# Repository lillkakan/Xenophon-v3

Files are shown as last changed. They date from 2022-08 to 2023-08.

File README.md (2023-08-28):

# Xenophon v3 split keyboard

Xenophon is a split keyboard with a design based on the ErgoDox EZ but for less keys for the thumps and another layout for the side keys.

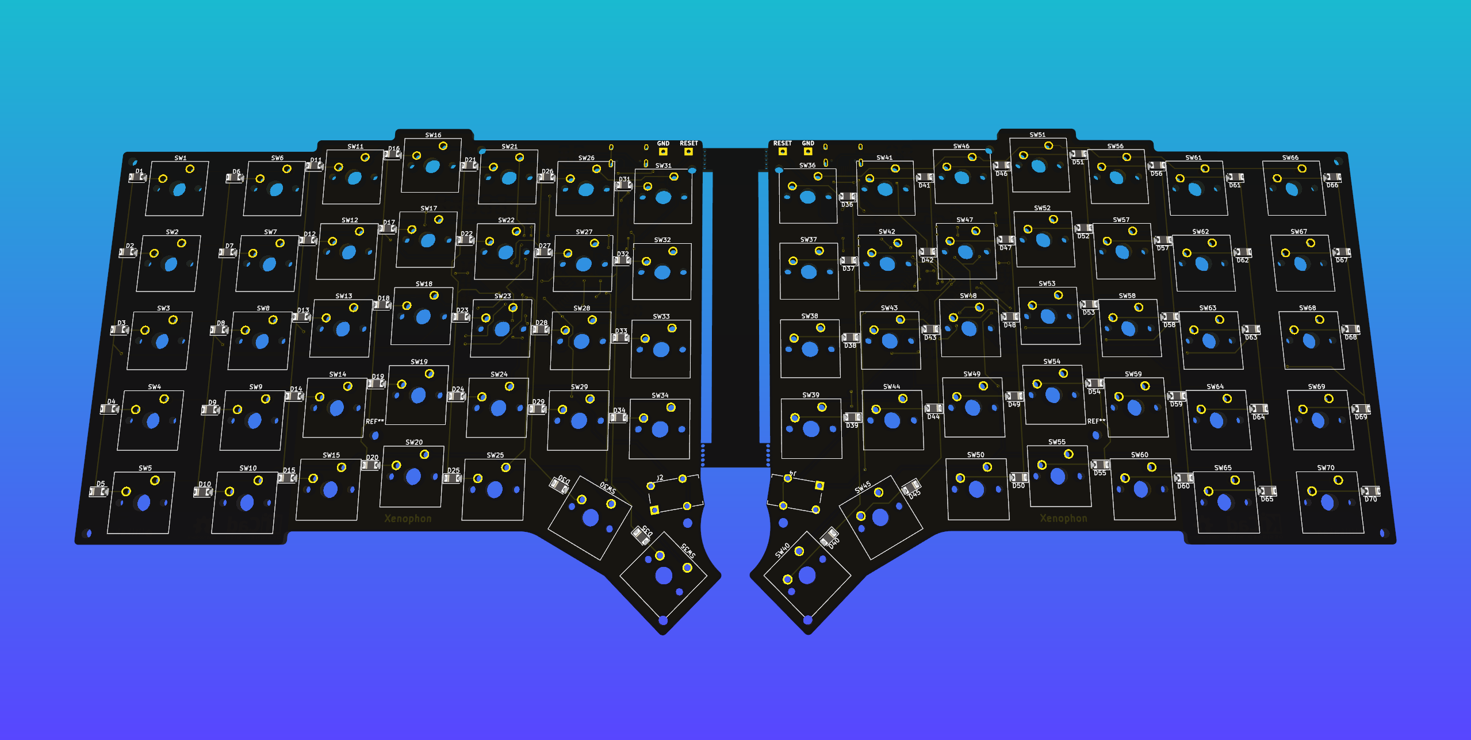
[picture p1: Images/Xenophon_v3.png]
The PCB for the keyboard.


## Features

### Ortholinear design

The keyboard features an ortholinear design based on the ErgoDox EZ.

### 70 buttons

The keyboard features 70 buttons to replicate a standard 60% keyboard as much as possible.
The Default layout is in swedish and has all the letters and numbers.

### TRS jack connection

The PCB is designed with a trs jack nicley placed between the tilted keys.
The two processors sent data through the serial bitbang protocol.

### Smart flashing design

With Usb on both sides it's easy to flash both processors.

### USB-C

The PCB features two usb type c ports with capability to connect via a usb-c to usb-c cable or a standard usb-c to usb-a cable.

### 3D printable chassi

The chassi for the keyboard is 3D printable and is designed to be as small as possible while still protecting the PCB and the electrical components.

## Made with

Quantum Mechanical Keyboard Firmware: [qmk_firmware](https://github.com/qmk/qmk_firmware)

### Made with help from

Keyboard layout editor: [keyboard-layout-editor.com](http://www.keyboard-layout-editor.com/)

Parametric Mechanical Keycap Library: [KeyV2](https://github.com/rsheldiii/KeyV2)

Keyboard Firmware Builder: [kbfirmware.com](https://kbfirmware.com/)

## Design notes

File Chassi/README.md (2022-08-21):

# Xenophon

The base is made using FreeCAD and can be 3D printed and applied to the PCB directly.

The PCB features small stud holes which fits on the studs on the chassi.
Because these holes are small there is a stud tester i printed to confirm that my 3D printers settings would work.

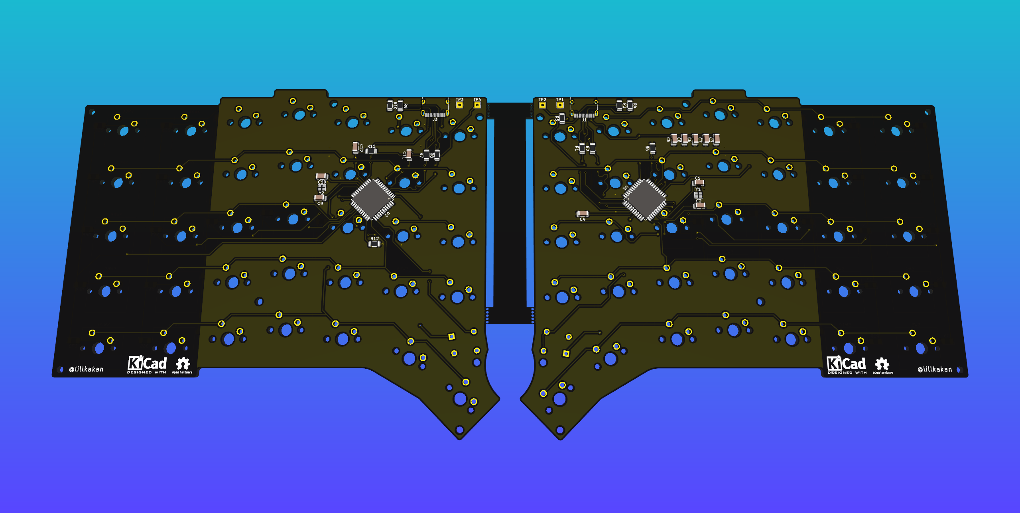
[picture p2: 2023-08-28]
Images/Xenophon_v3_back.png

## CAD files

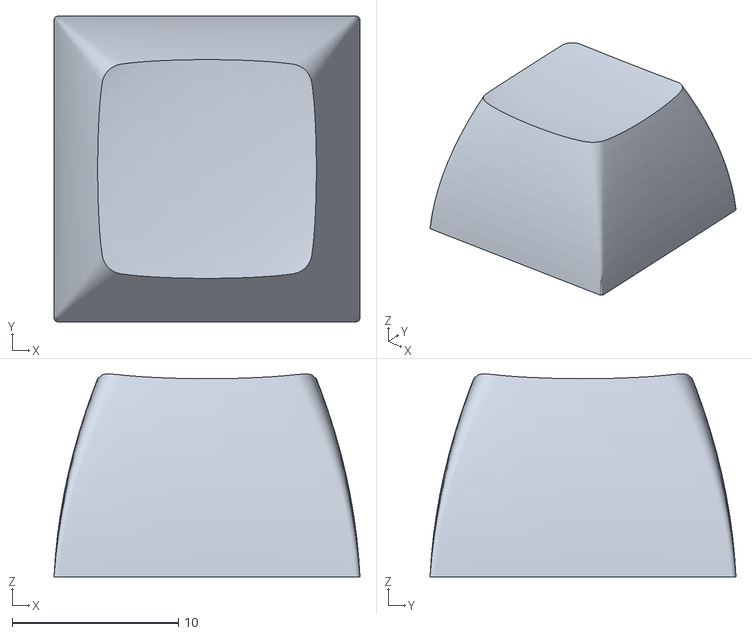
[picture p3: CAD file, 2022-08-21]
Chassi/Keys/sa.stl
18.4 x 18.4 x 12.2

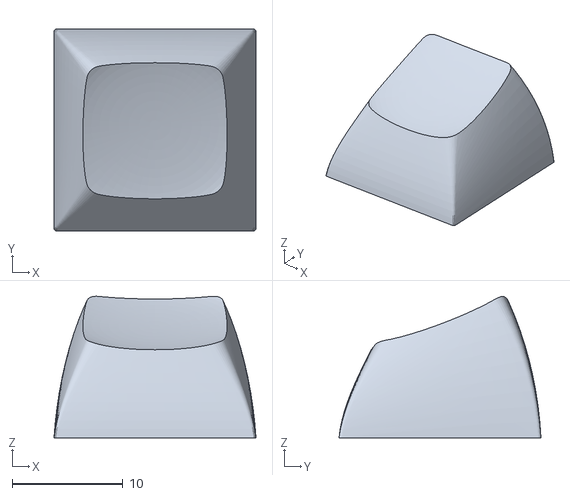
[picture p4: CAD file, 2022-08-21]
Chassi/Keys/dsa_r5.stl
18.2 x 18.2 x 12.8

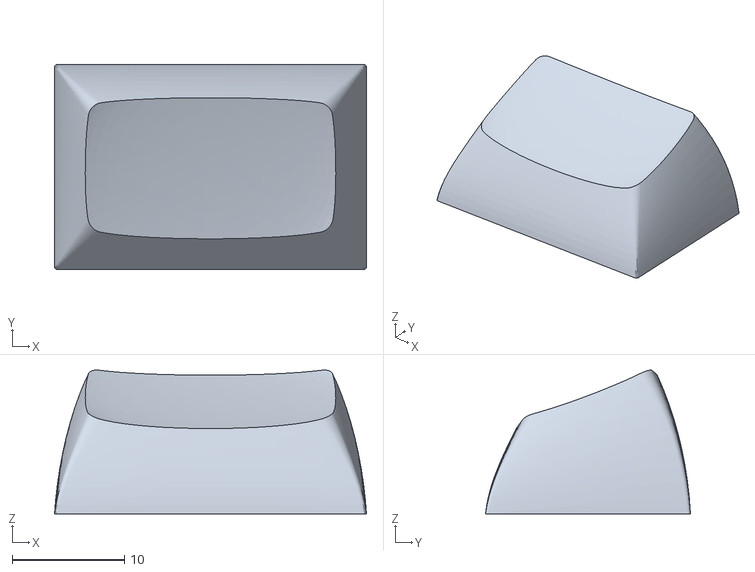
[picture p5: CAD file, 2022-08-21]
Chassi/Keys/dsa_r5_u1_5.stl
27.8 x 18.2 x 12.8

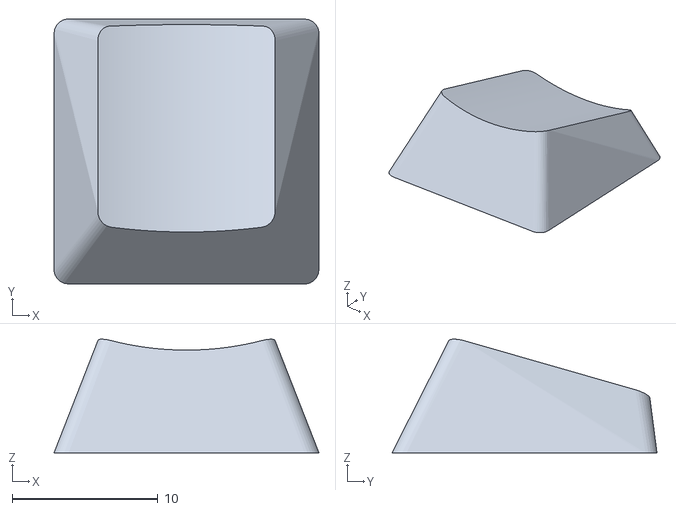
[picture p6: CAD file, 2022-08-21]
Chassi/Keys/dcs_r4.stl
18.2 x 18.2 x 7.79

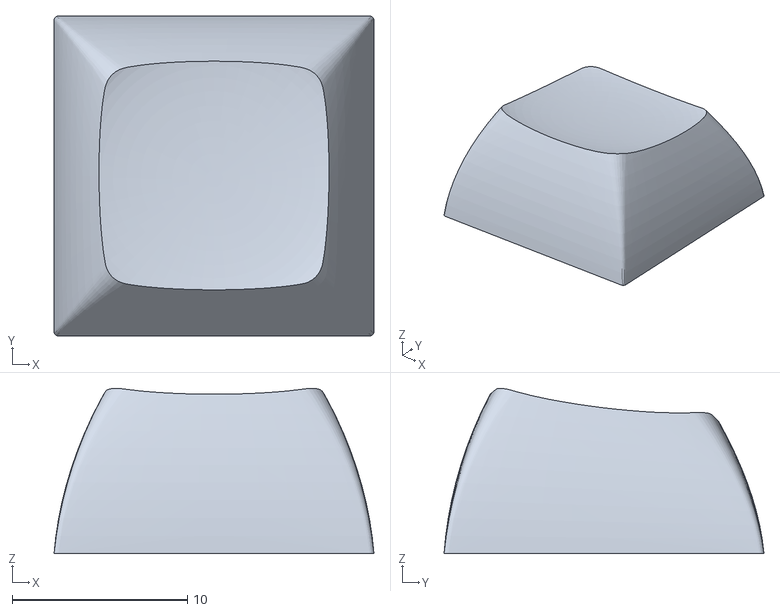
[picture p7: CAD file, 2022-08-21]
Chassi/Keys/dsa_r4.stl
18.2 x 18.2 x 9.43

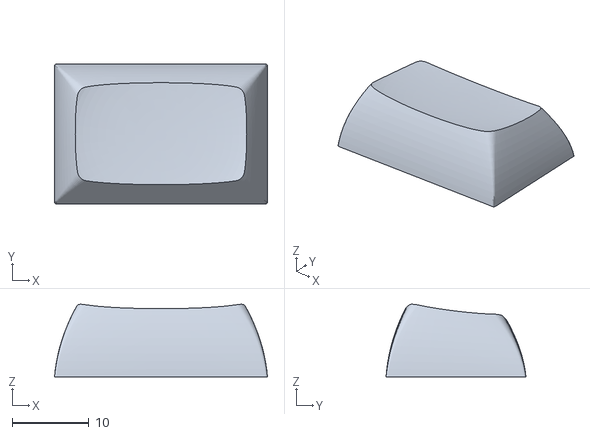
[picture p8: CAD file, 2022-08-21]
Chassi/Keys/dsa_r4_u1_5.stl
27.8 x 18.2 x 9.46

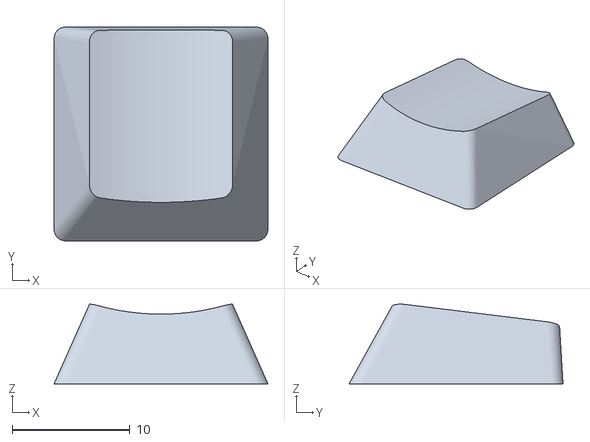
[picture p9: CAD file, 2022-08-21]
Chassi/Keys/dcs_r3.stl
18.2 x 18.2 x 6.77

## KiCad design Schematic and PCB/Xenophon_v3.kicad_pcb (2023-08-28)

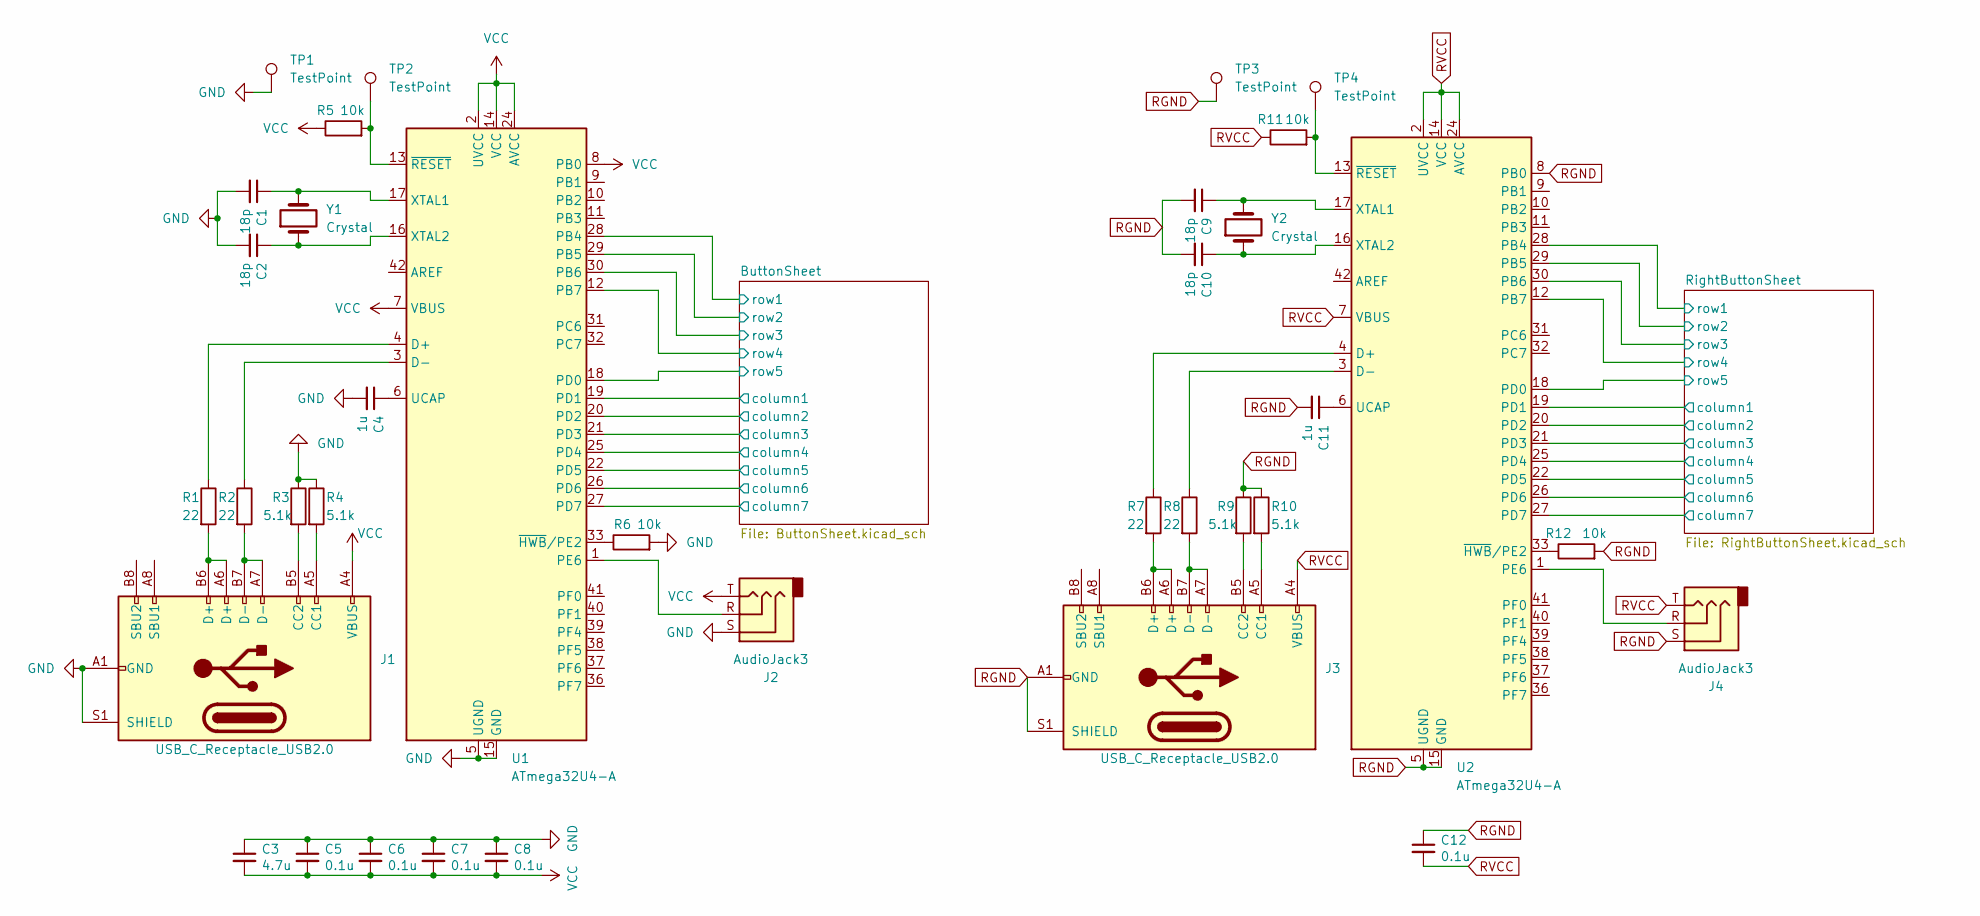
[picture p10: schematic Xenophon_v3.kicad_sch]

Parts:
C1, C2, C9, C10: 18p; C_1206_3216Metric
C3: 4.7u; C_1206_3216Metric
C4, C11: 1u; C_1206_3216Metric
C5, C6, C7, C8, C12: 0.1u; C_1206_3216Metric
J1, J3: USB_C_Receptacle_USB2.0; USB_C_Receptacle_HRO_TYPE-C-31-M-12
J2, J4: AudioJack3; Jack_3.5mm_Switronic_ST-005-G_horizontal
R1, R2, R7, R8: 22; R_1206_3216Metric
R3, R4, R9, R10: 5.1k; R_1206_3216Metric
R5, R6, R11, R12: 10k; R_1206_3216Metric
TP1, TP2, TP3, TP4: TestPoint; TestPoint_THTPad_2.0x2.0mm_Drill1.0mm
U1, U2: ATmega32U4-A; TQFP-44_10x10mm_P0.8mm
Y1, Y2: Crystal; Crystal_SMD_2016-4Pin_2.0x1.6mm

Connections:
/ButtonSheet/column1: U1.19 (PD1); also elsewhere on the board
/ButtonSheet/column2: U1.20 (PD2); also elsewhere on the board
/ButtonSheet/column3: U1.21 (PD3); also elsewhere on the board
/ButtonSheet/column4: U1.25 (PD4); also elsewhere on the board
/ButtonSheet/column5: U1.22 (PD5); also elsewhere on the board
/ButtonSheet/column6: U1.26 (PD6); also elsewhere on the board
/ButtonSheet/column7: U1.27 (PD7); also elsewhere on the board
/ButtonSheet/row1: U1.28 (PB4); also elsewhere on the board
/ButtonSheet/row2: U1.29 (PB5); also elsewhere on the board
/ButtonSheet/row3: U1.30 (PB6); also elsewhere on the board
/ButtonSheet/row4: U1.12 (PB7); also elsewhere on the board
/ButtonSheet/row5: U1.18 (PD0); also elsewhere on the board
/RightButtonSheet/column1: U2.19 (PD1); also elsewhere on the board
/RightButtonSheet/column2: U2.20 (PD2); also elsewhere on the board
/RightButtonSheet/column3: U2.21 (PD3); also elsewhere on the board
/RightButtonSheet/column4: U2.25 (PD4); also elsewhere on the board
/RightButtonSheet/column5: U2.22 (PD5); also elsewhere on the board
/RightButtonSheet/column6: U2.26 (PD6); also elsewhere on the board
/RightButtonSheet/column7: U2.27 (PD7); also elsewhere on the board
/RightButtonSheet/row1: U2.28 (PB4); also elsewhere on the board
/RightButtonSheet/row2: U2.29 (PB5); also elsewhere on the board
/RightButtonSheet/row3: U2.30 (PB6); also elsewhere on the board
/RightButtonSheet/row4: U2.12 (PB7); also elsewhere on the board
/RightButtonSheet/row5: U2.18 (PD0); also elsewhere on the board
GND: C1.2, C2.2, C3.1, C4.2, C5.1, C6.1, C7.1, C8.1, J1.A1 (GND), J1.A12 (GND), J1.B1 (GND), J1.B12 (GND), J1.S1 (SHIELD), J2.S, R3.1, R4.1, R6.2, TP1.1, U1.5 (UGND), U1.15 (GND), U1.23 (GND), U1.35 (GND), U1.43 (GND), Y1.3, Y1.4
unnamed: C1.1, U1.17 (XTAL1), Y1.2
unnamed: C2.1, U1.16 (XTAL2), Y1.1
unnamed: C4.1, U1.6 (UCAP)
unnamed: C9.1, U2.17 (XTAL1), Y2.2
unnamed: C10.1, U2.16 (XTAL2), Y2.1
unnamed: C11.1, U2.6 (UCAP)
unnamed: J1.A5 (CC1), R4.2
unnamed: J1.A6 (D+), J1.B6 (D+), R1.2
unnamed: J1.A7 (D-), J1.B7 (D-), R2.2
unnamed: J1.B5 (CC2), R3.2
unnamed: J2.R, U1.1 (PE6)
unnamed: J3.A5 (CC1), R10.2
unnamed: J3.B5 (CC2), R9.2
unnamed: J3.A6 (D+), J3.B6 (D+), R7.2
unnamed: J3.A7 (D-), J3.B7 (D-), R8.2
unnamed: J4.R, U2.1 (PE6)
unnamed: R1.1, U1.4 (D+)
unnamed: R2.1, U1.3 (D-)
unnamed: R5.2, TP2.1, U1.13 (~RESET)
unnamed: R6.1, U1.33 (~HWB/PE2)
unnamed: R7.1, U2.4 (D+)
unnamed: R8.1, U2.3 (D-)
unnamed: R11.2, TP4.1, U2.13 (~RESET)
unnamed: R12.1, U2.33 (~HWB/PE2)
RGND: C9.2, C10.2, C11.2, C12.1, J3.A1 (GND), J3.A12 (GND), J3.B1 (GND), J3.B12 (GND), J3.S1 (SHIELD), J4.S, R9.1, R10.1, R12.2, TP3.1, U2.5 (UGND), U2.8 (PB0), U2.15 (GND), U2.23 (GND), U2.35 (GND), U2.43 (GND), Y2.3, Y2.4
RVCC: C12.2, J3.A4 (VBUS), J3.A9 (VBUS), J3.B4 (VBUS), J3.B9 (VBUS), J4.T, R11.1, U2.2 (UVCC), U2.7 (VBUS), U2.14 (VCC), U2.24 (AVCC), U2.34 (VCC), U2.44 (AVCC)
VCC: C3.2, C5.2, C6.2, C7.2, C8.2, J1.A4 (VBUS), J1.A9 (VBUS), J1.B4 (VBUS), J1.B9 (VBUS), J2.T, R5.1, U1.2 (UVCC), U1.7 (VBUS), U1.8 (PB0), U1.14 (VCC), U1.24 (AVCC), U1.34 (VCC), U1.44 (AVCC)

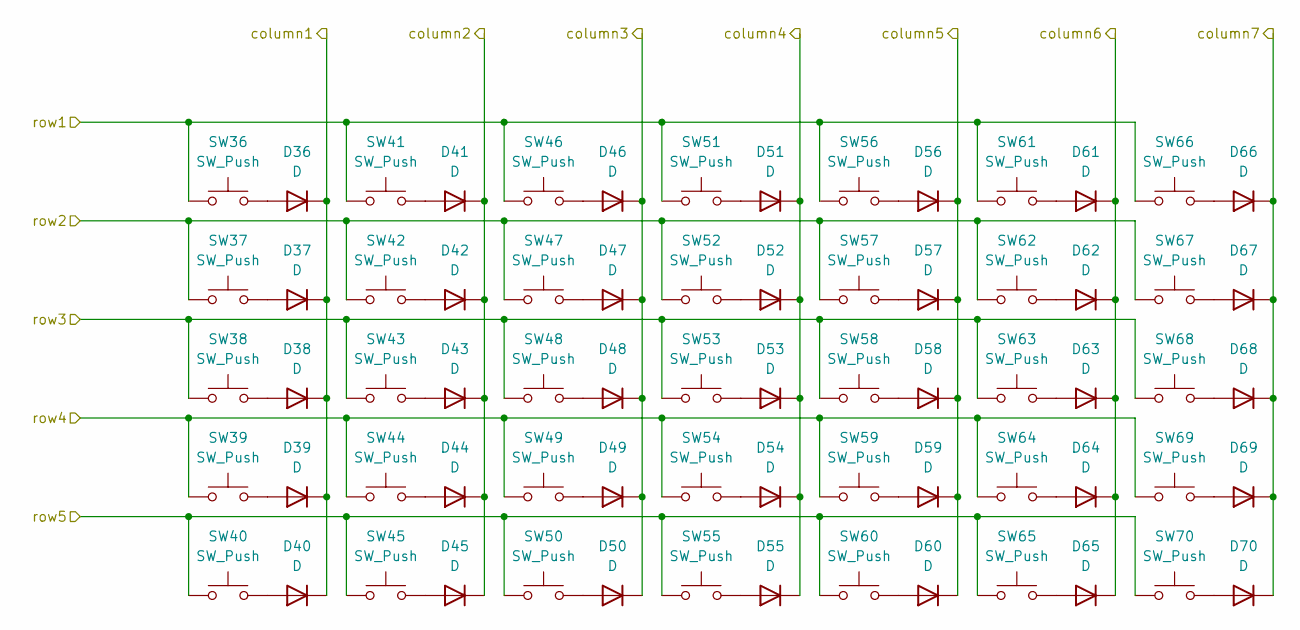
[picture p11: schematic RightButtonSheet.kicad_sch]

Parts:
D36, D37, D38, D39, D40, D41, D42, D43, D44, D45, D46, D47, D48, D49, D50, D51, D52, D53, D54, D55, D56, D57, D58, D59, D60, D61, D62, D63, D64, D65, D66, D67, D68, D69, D70: D; D_1206_3216Metric
SW36, SW37, SW38, SW39, SW40, SW41, SW42, SW43, SW44, SW45, SW46, SW47, SW48, SW49, SW50, SW51, SW52, SW53, SW54, SW55, SW56, SW57, SW58, SW59, SW60, SW61, SW62, SW63, SW64, SW65: SW_Push; SW_Cherry_MX_1.00u_PCB
SW66, SW67, SW68, SW69, SW70: SW_Push; SW_Cherry_MX_1.50u_PCB

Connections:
/RightButtonSheet/column1: D36.1 (K), D37.1 (K), D38.1 (K), D39.1 (K), D40.1 (K); also elsewhere on the board
/RightButtonSheet/column2: D41.1 (K), D42.1 (K), D43.1 (K), D44.1 (K), D45.1 (K); also elsewhere on the board
/RightButtonSheet/column3: D46.1 (K), D47.1 (K), D48.1 (K), D49.1 (K), D50.1 (K); also elsewhere on the board
/RightButtonSheet/column4: D51.1 (K), D52.1 (K), D53.1 (K), D54.1 (K), D55.1 (K); also elsewhere on the board
/RightButtonSheet/column5: D56.1 (K), D57.1 (K), D58.1 (K), D59.1 (K), D60.1 (K); also elsewhere on the board
/RightButtonSheet/column6: D61.1 (K), D62.1 (K), D63.1 (K), D64.1 (K), D65.1 (K); also elsewhere on the board
/RightButtonSheet/column7: D66.1 (K), D67.1 (K), D68.1 (K), D69.1 (K), D70.1 (K); also elsewhere on the board
/RightButtonSheet/row1: SW36.1, SW41.1, SW46.1, SW51.1, SW56.1, SW61.1, SW66.1; also elsewhere on the board
/RightButtonSheet/row2: SW37.1, SW42.1, SW47.1, SW52.1, SW57.1, SW62.1, SW67.1; also elsewhere on the board
/RightButtonSheet/row3: SW38.1, SW43.1, SW48.1, SW53.1, SW58.1, SW63.1, SW68.1; also elsewhere on the board
/RightButtonSheet/row4: SW39.1, SW44.1, SW49.1, SW54.1, SW59.1, SW64.1, SW69.1; also elsewhere on the board
/RightButtonSheet/row5: SW40.1, SW45.1, SW50.1, SW55.1, SW60.1, SW65.1, SW70.1; also elsewhere on the board
unnamed: D36.2 (A), SW36.2
unnamed: D37.2 (A), SW37.2
unnamed: D38.2 (A), SW38.2
unnamed: D39.2 (A), SW39.2
unnamed: D40.2 (A), SW40.2
unnamed: D41.2 (A), SW41.2
unnamed: D42.2 (A), SW42.2
unnamed: D43.2 (A), SW43.2
unnamed: D44.2 (A), SW44.2
unnamed: D45.2 (A), SW45.2
unnamed: D46.2 (A), SW46.2
unnamed: D47.2 (A), SW47.2
unnamed: D48.2 (A), SW48.2
unnamed: D49.2 (A), SW49.2
unnamed: D50.2 (A), SW50.2
unnamed: D51.2 (A), SW51.2
unnamed: D52.2 (A), SW52.2
unnamed: D53.2 (A), SW53.2
unnamed: D54.2 (A), SW54.2
unnamed: D55.2 (A), SW55.2
unnamed: D56.2 (A), SW56.2
unnamed: D57.2 (A), SW57.2
unnamed: D58.2 (A), SW58.2
unnamed: D59.2 (A), SW59.2
unnamed: D60.2 (A), SW60.2
unnamed: D61.2 (A), SW61.2
unnamed: D62.2 (A), SW62.2
unnamed: D63.2 (A), SW63.2
unnamed: D64.2 (A), SW64.2
unnamed: D65.2 (A), SW65.2
unnamed: D66.2 (A), SW66.2
unnamed: D67.2 (A), SW67.2
unnamed: D68.2 (A), SW68.2
unnamed: D69.2 (A), SW69.2
unnamed: D70.2 (A), SW70.2

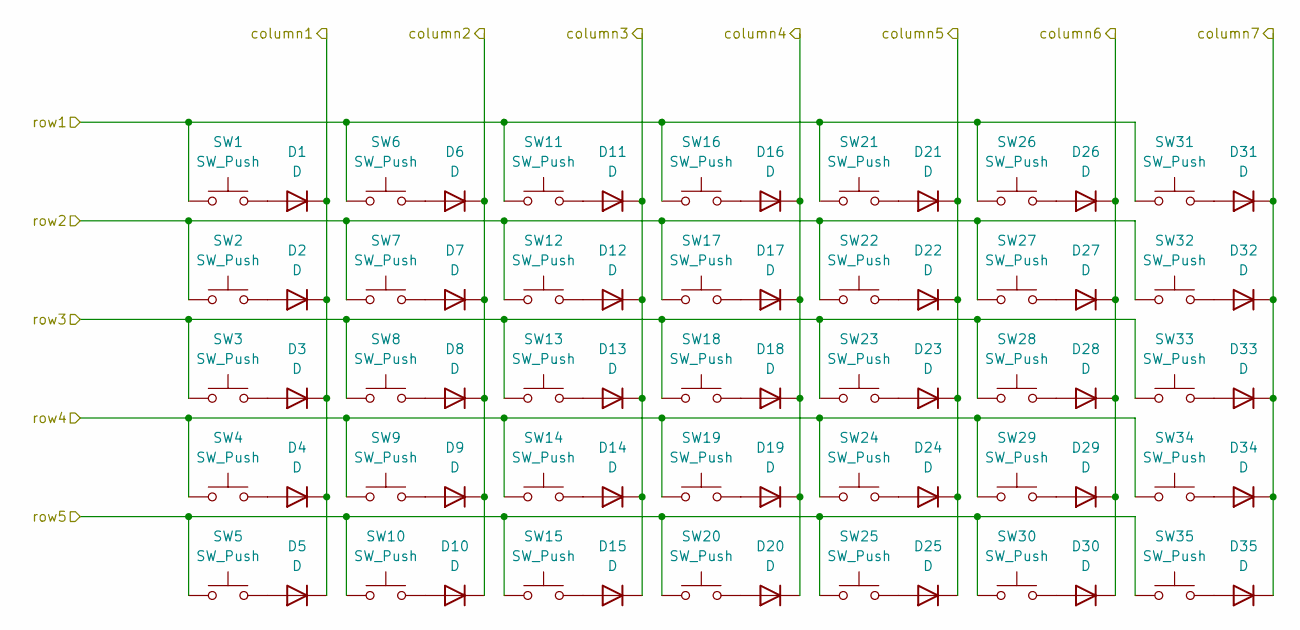
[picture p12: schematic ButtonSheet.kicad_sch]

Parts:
D1, D2, D3, D4, D5, D6, D7, D8, D9, D10, D11, D12, D13, D14, D15, D16, D17, D18, D19, D20, D21, D22, D23, D24, D25, D26, D27, D28, D29, D30, D31, D32, D33, D34, D35: D; D_1206_3216Metric
SW1, SW2, SW3, SW4, SW5: SW_Push; SW_Cherry_MX_1.50u_PCB
SW6, SW7, SW8, SW9, SW10, SW11, SW12, SW13, SW14, SW15, SW16, SW17, SW18, SW19, SW20, SW21, SW22, SW23, SW24, SW25, SW26, SW27, SW28, SW29, SW30, SW31, SW32, SW33, SW34, SW35: SW_Push; SW_Cherry_MX_1.00u_PCB

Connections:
/ButtonSheet/column1: D1.1 (K), D2.1 (K), D3.1 (K), D4.1 (K), D5.1 (K); also elsewhere on the board
/ButtonSheet/column2: D6.1 (K), D7.1 (K), D8.1 (K), D9.1 (K), D10.1 (K); also elsewhere on the board
/ButtonSheet/column3: D11.1 (K), D12.1 (K), D13.1 (K), D14.1 (K), D15.1 (K); also elsewhere on the board
/ButtonSheet/column4: D16.1 (K), D17.1 (K), D18.1 (K), D19.1 (K), D20.1 (K); also elsewhere on the board
/ButtonSheet/column5: D21.1 (K), D22.1 (K), D23.1 (K), D24.1 (K), D25.1 (K); also elsewhere on the board
/ButtonSheet/column6: D26.1 (K), D27.1 (K), D28.1 (K), D29.1 (K), D30.1 (K); also elsewhere on the board
/ButtonSheet/column7: D31.1 (K), D32.1 (K), D33.1 (K), D34.1 (K), D35.1 (K); also elsewhere on the board
/ButtonSheet/row1: SW1.1, SW6.1, SW11.1, SW16.1, SW21.1, SW26.1, SW31.1; also elsewhere on the board
/ButtonSheet/row2: SW2.1, SW7.1, SW12.1, SW17.1, SW22.1, SW27.1, SW32.1; also elsewhere on the board
/ButtonSheet/row3: SW3.1, SW8.1, SW13.1, SW18.1, SW23.1, SW28.1, SW33.1; also elsewhere on the board
/ButtonSheet/row4: SW4.1, SW9.1, SW14.1, SW19.1, SW24.1, SW29.1, SW34.1; also elsewhere on the board
/ButtonSheet/row5: SW5.1, SW10.1, SW15.1, SW20.1, SW25.1, SW30.1, SW35.1; also elsewhere on the board
unnamed: D1.2 (A), SW1.2
unnamed: D2.2 (A), SW2.2
unnamed: D3.2 (A), SW3.2
unnamed: D4.2 (A), SW4.2
unnamed: D5.2 (A), SW5.2
unnamed: D6.2 (A), SW6.2
unnamed: D7.2 (A), SW7.2
unnamed: D8.2 (A), SW8.2
unnamed: D9.2 (A), SW9.2
unnamed: D10.2 (A), SW10.2
unnamed: D11.2 (A), SW11.2
unnamed: D12.2 (A), SW12.2
unnamed: D13.2 (A), SW13.2
unnamed: D14.2 (A), SW14.2
unnamed: D15.2 (A), SW15.2
unnamed: D16.2 (A), SW16.2
unnamed: D17.2 (A), SW17.2
unnamed: D18.2 (A), SW18.2
unnamed: D19.2 (A), SW19.2
unnamed: D20.2 (A), SW20.2
unnamed: D21.2 (A), SW21.2
unnamed: D22.2 (A), SW22.2
unnamed: D23.2 (A), SW23.2
unnamed: D24.2 (A), SW24.2
unnamed: D25.2 (A), SW25.2
unnamed: D26.2 (A), SW26.2
unnamed: D27.2 (A), SW27.2
unnamed: D28.2 (A), SW28.2
unnamed: D29.2 (A), SW29.2
unnamed: D30.2 (A), SW30.2
unnamed: D31.2 (A), SW31.2
unnamed: D32.2 (A), SW32.2
unnamed: D33.2 (A), SW33.2
unnamed: D34.2 (A), SW34.2
unnamed: D35.2 (A), SW35.2

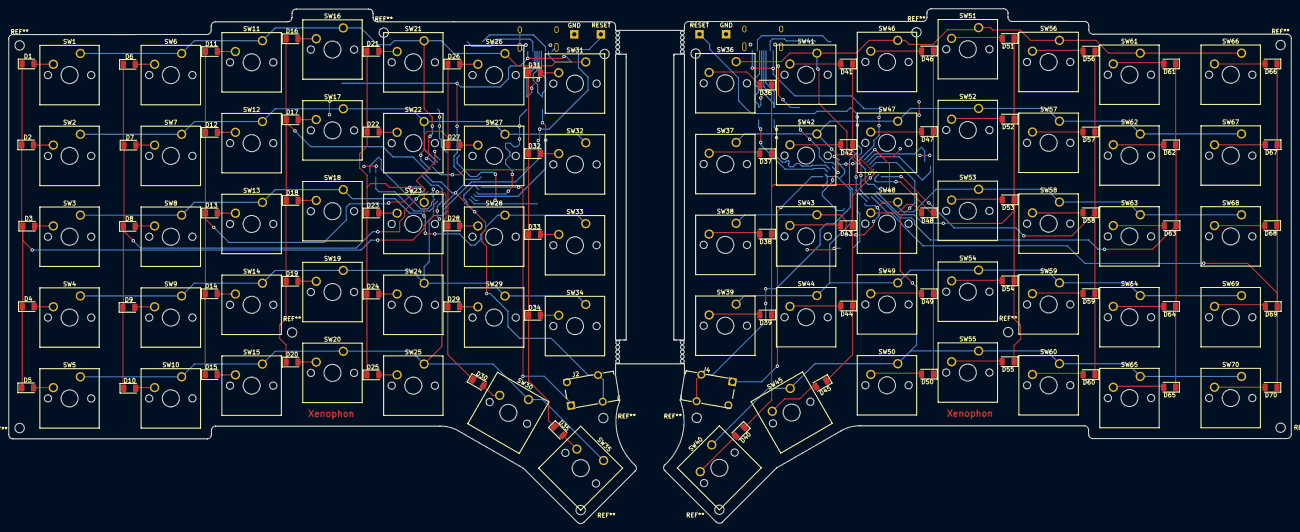
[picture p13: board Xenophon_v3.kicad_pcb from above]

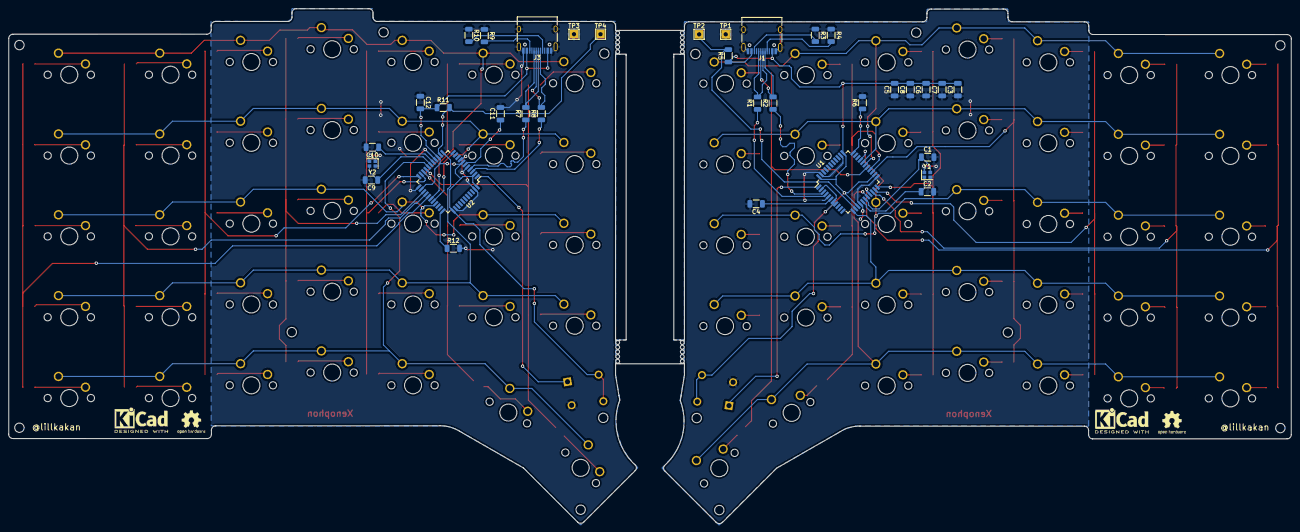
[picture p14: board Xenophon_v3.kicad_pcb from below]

Board: 2 copper layers, 301.5 x 121.0 mm, 176 parts (34 on the bottom side), 122 nets.

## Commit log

2022-08-21 First design
    [ButtonSheet.kicad_sch, RightButtonSheet.kicad_sch, Xenophon_v3.kicad_pcb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]
2022-08-21 Small rerouting fixes
    [Xenophon_v3.kicad_pcb]
2022-08-21 Panelized the pcb
    [Xenophon_v3.kicad_pcb, Xenophon_v3.kicad_sch]
2023-08-28 Updated readme and qmk code
    [Xenophon_v3.kicad_pcb]
2023-08-28 Updated gerber
